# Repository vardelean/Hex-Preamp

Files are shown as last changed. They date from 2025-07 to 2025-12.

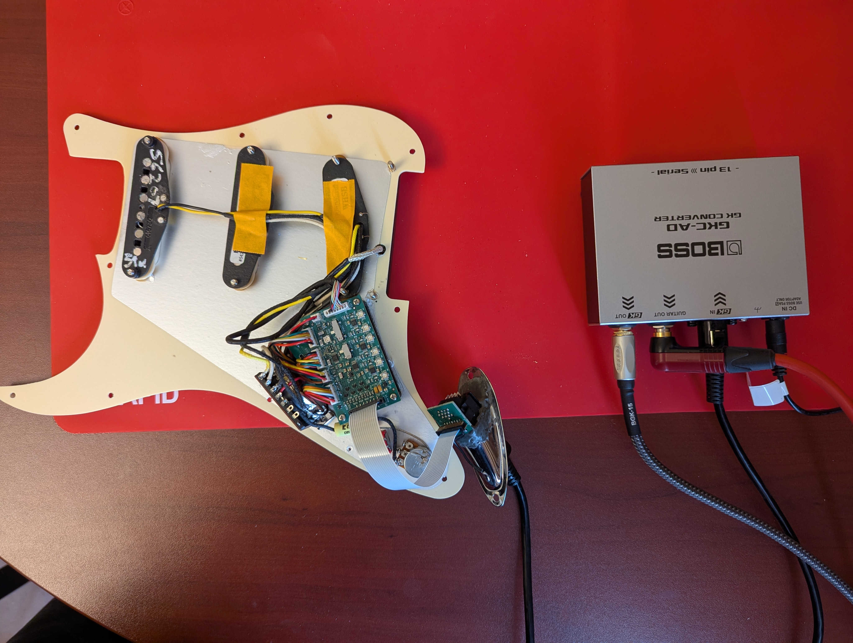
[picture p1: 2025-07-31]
Pics/Strat_Installation.jpg

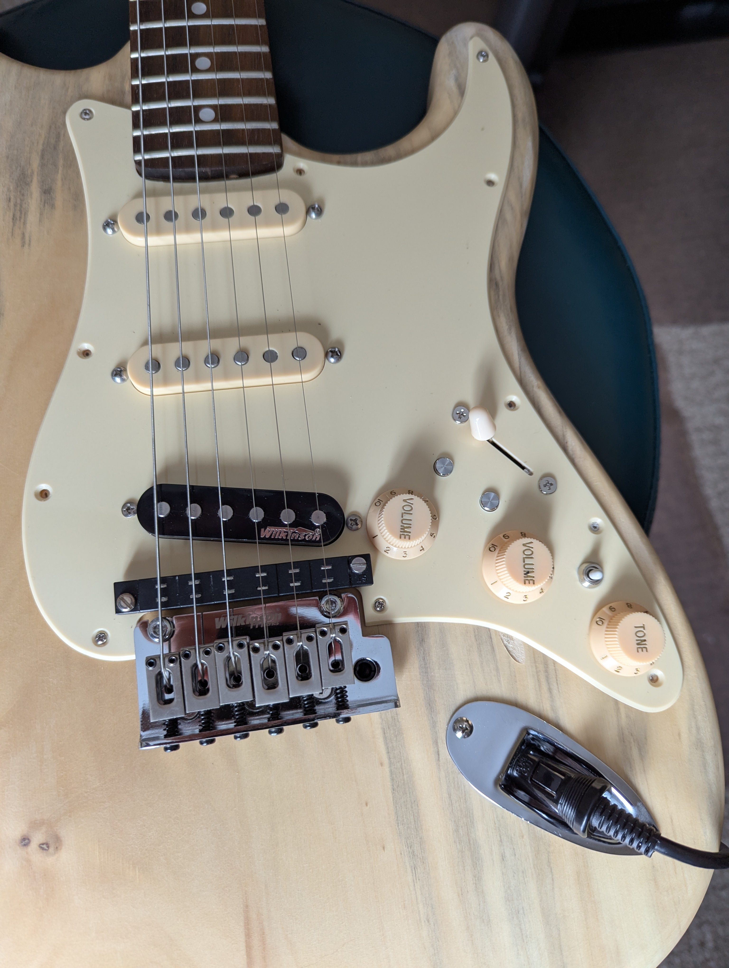
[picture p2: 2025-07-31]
Pics/Temporary install.jpg

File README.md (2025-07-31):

# Hex-Preamp
A GK-3 Compatible Hexaphonic Pickup Preamp Experiment

## Design Considerations

The motivation for this project was to build a hexaphonic preamp that is Boss GK-3 compatible but with a common Mag/Synth Volume control and a Mag/Synth Balance control. I could have used a GK-KIT-GT3 and try to modify it, but I already had a divided pickup (a hex pickup made by Shadow, left over from an ATG Luthier Kit), so to me at least, it just made sense to build the electronics.
This design is based on the original GK-3 schematic as published by Boss in their service manual. 
In addition to a common Volume control for Mag and Synth, I placed a Balance control pot with a center detent to adjust the balance between the Mag pickups and the Synth sound. Since half of this pot (P1B) works as per the original Volume control in GK-3 Synth and Mix mode, it can also be programmed for several other functions. The programming for this control is done via the Boss software, just like programming the Volume control in a GK-3. 
Only one cable is coming out of the guitar, the 13pin cable. I didn’t want 2 connectors, one for the GK-3 (13 pin) and one for the guitar’s jack. Therefore, I replaced my Strat’s jack with a 13 pin DIN connector.
Since I installed this board in a Strat, the 3 potentiometer knobs are now Volume, Balance and Tone.
The Volume and Balance work as explained above, and the Tone is placed at the output of the 5-way pickup selector switch. With this wiring, there is just one Tone pot for the 3 magnetic pickups. The Tone control has no impact on Synth sounds.

## Other Changes and Modifications to the GK-3 Design
- I used better quality opamps (lower noise, lower distortion, and lower power consumption).
- Adjustable gain for each string. I have a GK-5 installed on another Strat that I use with my VG-800, and I noticed that a hotter output from the pickups would benefit the system’s SNR and the note recognition algorithms. Since on this kit I was going to use a Shadow Hex pickup, I had no idea what the correct gain should be, so I decided for a gain trim per string.
- Adjustable gain for the guitar’s main pickups: this is to balance the mag sound compared to the Synth levels.
- Selectable input impedance for the guitar’s pickups to accommodate either SC or HB pickups (SW2). Not really needed, but I’m thinking on replacing the bridge pickup with a humbucker at one point, so this switch may come in handy.
- Selectable input capacitance for the guitar’s pickups to emulate different cable lengths (SW1). I prefer the sound of my SC pickups through a short cable. A preamp removes the cable’s capacitance impact on the pickup’s resonance frequency, so I decided to add a switch that could emulate the cable’s capacitance.
- The Volume control, P2, is a supposed to be a stereo pot, half Log / half Lin.  I couldn't find such a pot, so I decided to make my own custom pot out of two stereo pots, one Log and one Lin.
- The Balance pot, P1, is a stereo Lin pot with a center detent. 
- The schematic shows a toggle switch for the UP/DOWN selector (SW3). In my Strat implementation, I used 2 separate tactile switches instead. Either option works well.
- The wiring from the main board’s J2 connector to the 13pin DIN connector was done via an FFC cable. Feeding the FFC cable from the main board to the 13pin connector in a Strat body turned out to be a bit of a challenge. If I ever decide to make another version of this board, I may consider using a different type of cable.

## Power 
The board is powered via the 13pin connector, just like the regular GK-3 Kit. 

## Connectors
JST 1.5mm connectors everywhere except for the FPC connector.

## Files

- 13PIN_Connector_Board/Hex_Out - Files for the 13pin connector adapter board
- G13_Breakout_Board - Files for a test board, allows to look at the 13pins signals while conencted to the Boss equipment
- GI13_Hex_Preamp - Main files for the Guitar Interface 13 pin Hex Preamp
- Pics - Repository for pics and images of the board installation

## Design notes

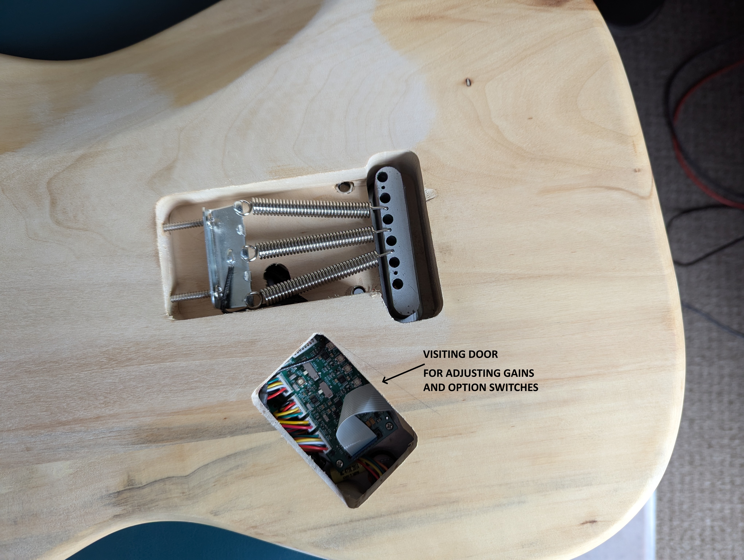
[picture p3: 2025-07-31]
Pics/Controls_Backdoor.jpg

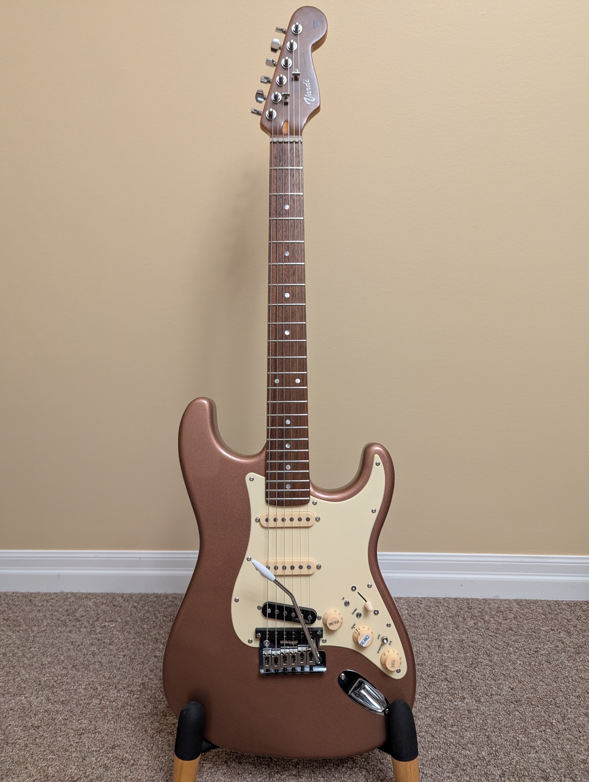
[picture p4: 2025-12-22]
Pics/GK_3_FInished_1.jpg

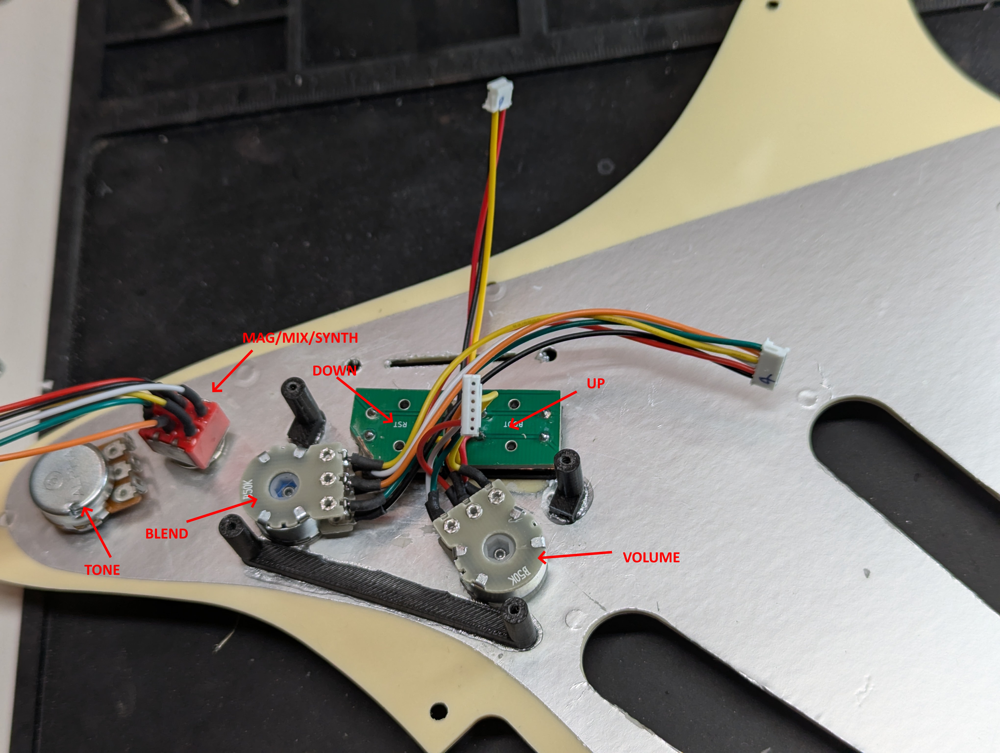
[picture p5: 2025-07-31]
Pics/Support_For_Hex_Preamp.jpg

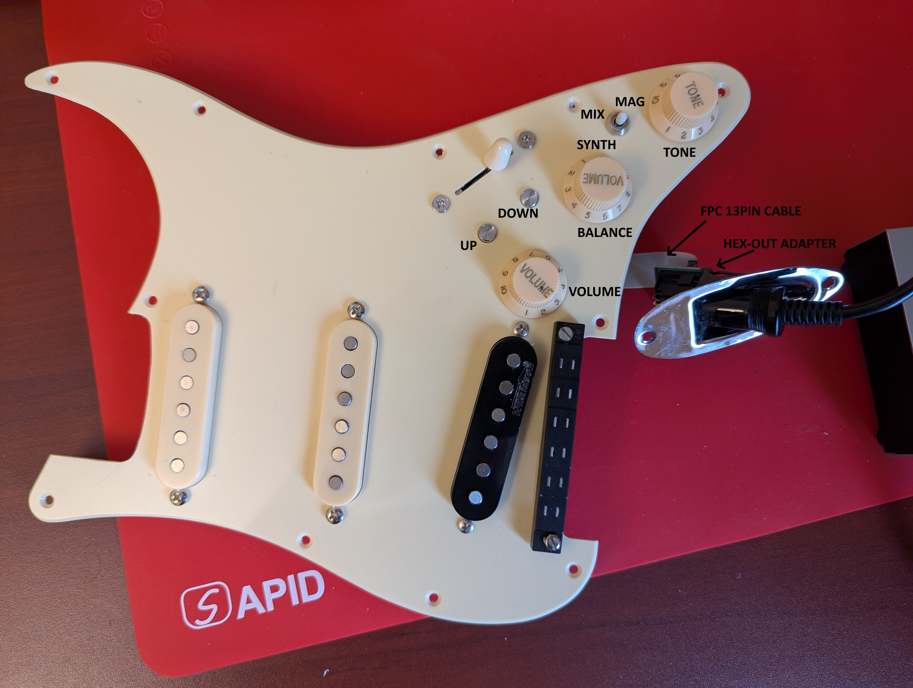
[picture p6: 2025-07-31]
Pics/Strat_Pickguard.jpg

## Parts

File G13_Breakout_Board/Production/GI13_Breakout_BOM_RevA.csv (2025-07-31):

Designator | Footprint | Quantity | Value | LCSC Part #
D1 | 0603 | 1 | +7V | 5973324507F
D2 | 0603 | 1 | -7V | 5990040007F
J1, J4 | PinHeader_1x07_P2.54mm_Vertical | 2 | Conn_01x07_Pin
J2, J3 | CUI_SDD-130J | 2 | SDD-130J | SDD-130J
J5 | PinHeader_1x02_P2.54mm_Vertical | 1 | Conn_01x07_Pin
R1, R2 | 0603 | 2 | 1K

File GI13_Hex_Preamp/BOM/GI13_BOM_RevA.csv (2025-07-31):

Reference | Value | Datasheet | Footprint | Qty | DNP | MPN | Description
C1,C2,C3,C4,C5,C14,C15,C16,C23,C25,C26,C29,C30,C35 | 0.1u | ~ | Capacitor_SMD:C_0603_1608Metric | 14 |  |  | Unpolarized capacitor
C6,C7,C8,C9,C10,C11,C28 | 220p | ~ | Capacitor_SMD:C_0603_1608Metric | 7 |  |  | Unpolarized capacitor
C12,C13 | 10u | ~ | Capacitor_Tantalum_SMD:CP_EIA-3216-18_Kemet-A | 2 |  |  | Polarized capacitor
C17,C18,C19,C20,C21,C22,C36,C37 | 1n0 | ~ | Capacitor_SMD:C_0603_1608Metric | 8 |  |  | Unpolarized capacitor
C24 | 10n | ~ | Capacitor_SMD:C_0603_1608Metric | 1 |  |  | Unpolarized capacitor
C27 | 470p | ~ | Capacitor_SMD:C_0603_1608Metric | 1 |  |  | Unpolarized capacitor
C31 | 47n | ~ | Capacitor_SMD:C_0805_2012Metric | 1 |  | C0805C473K3GECTU | Ceramic Capacitor COG
C32 | 47p | ~ | Capacitor_SMD:C_0603_1608Metric | 1 |  |  | Unpolarized capacitor
C33,C34,C38,C39 | 0.22u | https://search.murata.co.jp/Ceramy/image/img/A01X/G101/ENG/GRM31C5C1E224JE02-01A.pdf | Capacitor_SMD:C_1206_3216Metric | 4 |  | GRM31C5C1E224JE02L | CAP CER 0.22UF 25V C0G/NP0 1206
D1,D2,D3,D4,D5,D6,D7,D8 | 1SS302 | https://www.digikey.ca/en/models/5810203 | User_1:USM_TOS | 8 |  |  | DIODE ARRAY GP 80V 100MA SC-70
H1,H2,H3,H4 | MountingHole | ~ | MountingHole:MountingHole_2.2mm_M2_DIN965_Pad_TopBottom | 4 |  |  | Mounting Hole with connection
J1 | Conn_01x08_Pin_Box | ~ | Connector_JST:JST_ZH_B8B-ZR_1x08_P1.50mm_Vertical | 1 |  | B8B-ZH-K-S | Generic connector, single row, 01x08, script generated
J2 | SFW14S-2STE1LF | https://cdn.amphenol-cs.com/media/wysiwyg/files/documentation/datasheet/flex/flexconnectors_100mm_sfw_s.pdf | Connector_FFC-FPC:AMPHENOL_SFW14S-2STE1LF | 1 |  | SFW14S-2STE1LF | CONN FFC FPC VERT 14POS 1MM SMD
J3 | Conn_01x02_Pin | ~ | Connector_JST:JST_ZH_B2B-ZR_1x02_P1.50mm_Vertical | 1 |  |  | Generic connector, single row, 01x02, script generated
J4,J5,J7 | Conn_01x06_Pin | ~ | Connector_JST:JST_ZH_B6B-ZR_1x06_P1.50mm_Vertical | 3 |  |  | Generic connector, single row, 01x06, script generated (kicad-library-utils/schlib/autogen/connector/)
J6 | Conn_01x03 | ~ | Connector_JST:JST_ZH_B3B-ZR_1x03_P1.50mm_Vertical | 1 |  |  | Generic connector, single row, 01x03, script generated (kicad-library-utils/schlib/autogen/connector/)
R1,R2,R3,R4,R5,R6,R24,R29 | 5K1 | ~ | Resistor_SMD:R_0603_1608Metric | 8 |  |  | Resistor, US symbol
R7,R8,R9,R10,R11,R12,R13,R14 | 1K0 | ~ | Resistor_SMD:R_0603_1608Metric | 8 |  |  | Resistor, US symbol
R15,R16,R17 | 100R | ~ | Resistor_SMD:R_0603_1608Metric | 3 |  |  | Resistor, US symbol
R18,R20,R23,R26,R30,R33 | 51R | ~ | Resistor_SMD:R_0603_1608Metric | 6 |  |  | Resistor, US symbol
R19,R27 | 220K | ~ | Resistor_SMD:R_0603_1608Metric | 2 |  |  | Resistor, US symbol
R21,R22 | 249K | ~ | Resistor_SMD:R_0603_1608Metric | 2 |  |  | Resistor, US symbol
R25 | 10K | ~ | Resistor_SMD:R_0603_1608Metric | 1 |  |  | Resistor, US symbol
R28 | 5M1 | ~ | Resistor_SMD:R_0603_1608Metric | 1 |  |  | Resistor, US symbol
R31 | 6K81 | ~ | Resistor_SMD:R_0603_1608Metric | 1 |  |  | Resistor, US symbol
R32,R37 | 18K | ~ | Resistor_SMD:R_0603_1608Metric | 2 |  |  | Resistor, US symbol
R34 | 9K42 | ~ | Resistor_SMD:R_0603_1608Metric | 1 |  |  | Resistor, US symbol
R35 | 1K8 | ~ | Resistor_SMD:R_0603_1608Metric | 1 |  |  | Resistor, US symbol
R36 | 1K43 | ~ | Resistor_SMD:R_0603_1608Metric | 1 |  |  | Resistor, US symbol
RV1,RV2,RV3,RV4,RV5,RV6,RV7 | 20K | https://www.bourns.com/docs/Product-Datasheets/pvg3.pdf | Potentiometer_SMD:TRIM_PVG3G203C01R00 | 7 |  | PVG3G203C01R00 | TRIMMER 20K OHM 0.25W GW TOP ADJ
SW1 | CL-SB-13B-11T | https://www.nidec-copal-electronics.com/e/catalog/switch/cl-sb.pdf | Switches:CLSB13B11T | 1 |  | CLSB13B11T | Slide Switches slide , 1 pole 3 cont., side set., gull-wing, silver contact, 2mm knob
SW2 | CL-SB-12B-11T | https://www.nidec-copal-electronics.com/e/catalog/switch/cl-sb.pdf | Switches:CLSB12B01T | 1 |  | CLSB12B01T | Slide Switches slide , 1 pole 3 cont., side set., gull-wing, silver contact, 2mm knob
U1 | MCP1754S-5002xCB | http://ww1.microchip.com/downloads/en/DeviceDoc/20002276C.pdf | Package_TO_SOT_SMD:SOT-23 | 1 |  | MCP1754ST-5002E/CB | Fixed 150mA Low Dropout Voltage Regulator, Positive, 5V output, SOT-23
U2,U3,U4,U7 | OPA1692 | https://www.ti.com/lit/gpn/OPA1692 | Package_SO:MSOP-8_3x3mm_P0.65mm | 4 |  | OPA1692IDGKR | Audio Amplifier 2 Circuit Rail-to-Rail 8-VSSOP
U5 | TLV9302xDGK | https://www.ti.com/lit/ds/symlink/tlv9302.pdf | Package_SO:MSOP-8_3x3mm_P0.65mm | 1 |  | TLV9302IDGK | 40-V, 1-MHz, RRO Operational Amplifiers for Cost-Sensitive Systems, VSSOP-8
U6 | TLV9151IDBVR | https://www.ti.com/lit/gpn/tlv9151 | Package_TO_SOT_SMD:SOT-23-5 | 1 |  | TLV9151IDBVR | IC OPAMP GP 1 CIRCUIT SOT23-5

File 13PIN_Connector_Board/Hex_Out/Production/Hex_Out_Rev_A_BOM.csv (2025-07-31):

Designator | Footprint | Quantity | Value | LCSC Part #
J1 | AMPHENOL_SFW14S-2STE1LF | 1 | Conn_02x07_Odd_Even
J4 | CUI_SDD-130J | 1 | SDD-130J | SDD-130J

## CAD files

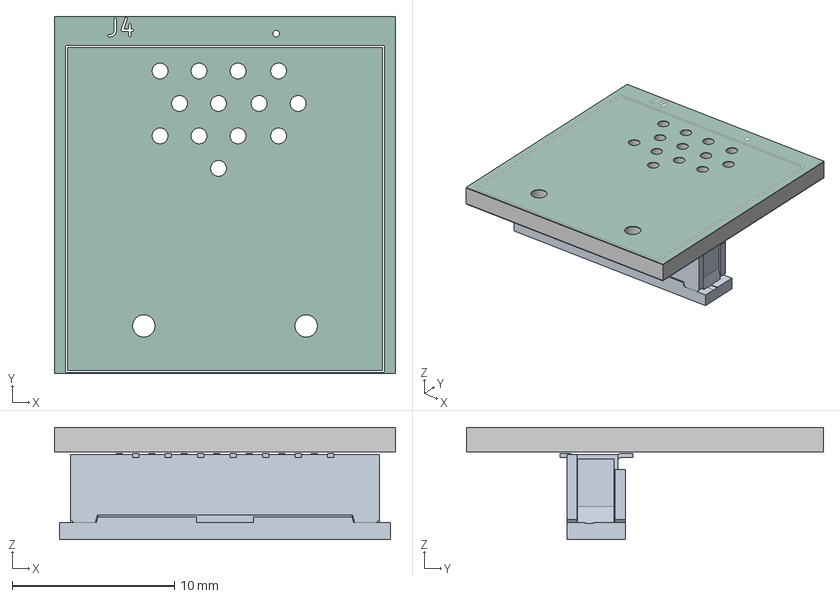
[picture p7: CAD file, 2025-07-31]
13PIN_Connector_Board/Hex_Out/Hex_Out_RevA_3D.step
21.0 x 22.0 x 6.97 mm
Hex_Out_RevA_3D 1.1
Hex_Out_silkscreen
Hex_Out_soldermask
Hex_Out_PCB

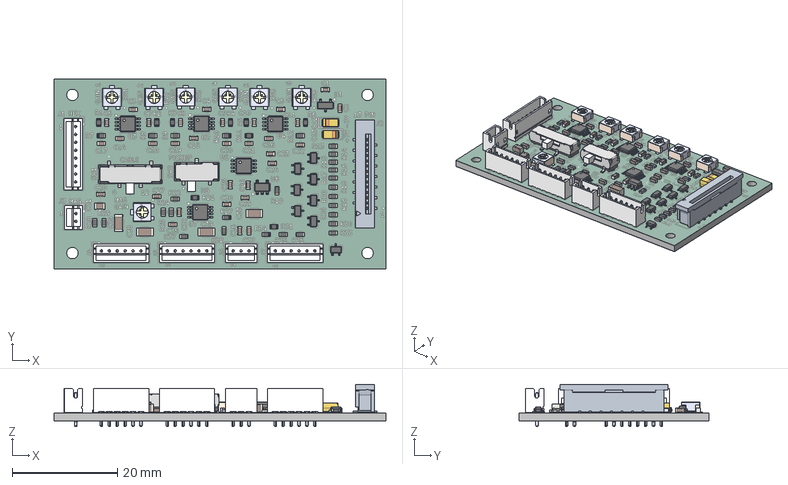
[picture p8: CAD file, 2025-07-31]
GI13_Hex_Preamp/3D/GI13_3D_RevA.step
63.0 x 36.0 x 8.00 mm
C_1206_3216Metric x 4
C_0603_1608Metric x 32
R_0603_1608Metric x 37
PVG3G203C01R00 x 7
BxB-ZR_3
pin_straight x 20
pin_Bent x 11
SOT-23-5
BxB-ZR_2
BxB-ZR_6 x 3
GI13_3D_RevA 1.33
MSOP-8_3x3mm_P0.65mm x 5
13B-11_c
3Side setting_s
SOT-23
C_0805_2012Metric
BxB-ZR_8
sc70-3 x 8
CP_EIA-3216-18_Kemet-A x 2
12B-11_c
2Side setting_s
GI13_silkscreen
GI13_soldermask
GI13_PCB

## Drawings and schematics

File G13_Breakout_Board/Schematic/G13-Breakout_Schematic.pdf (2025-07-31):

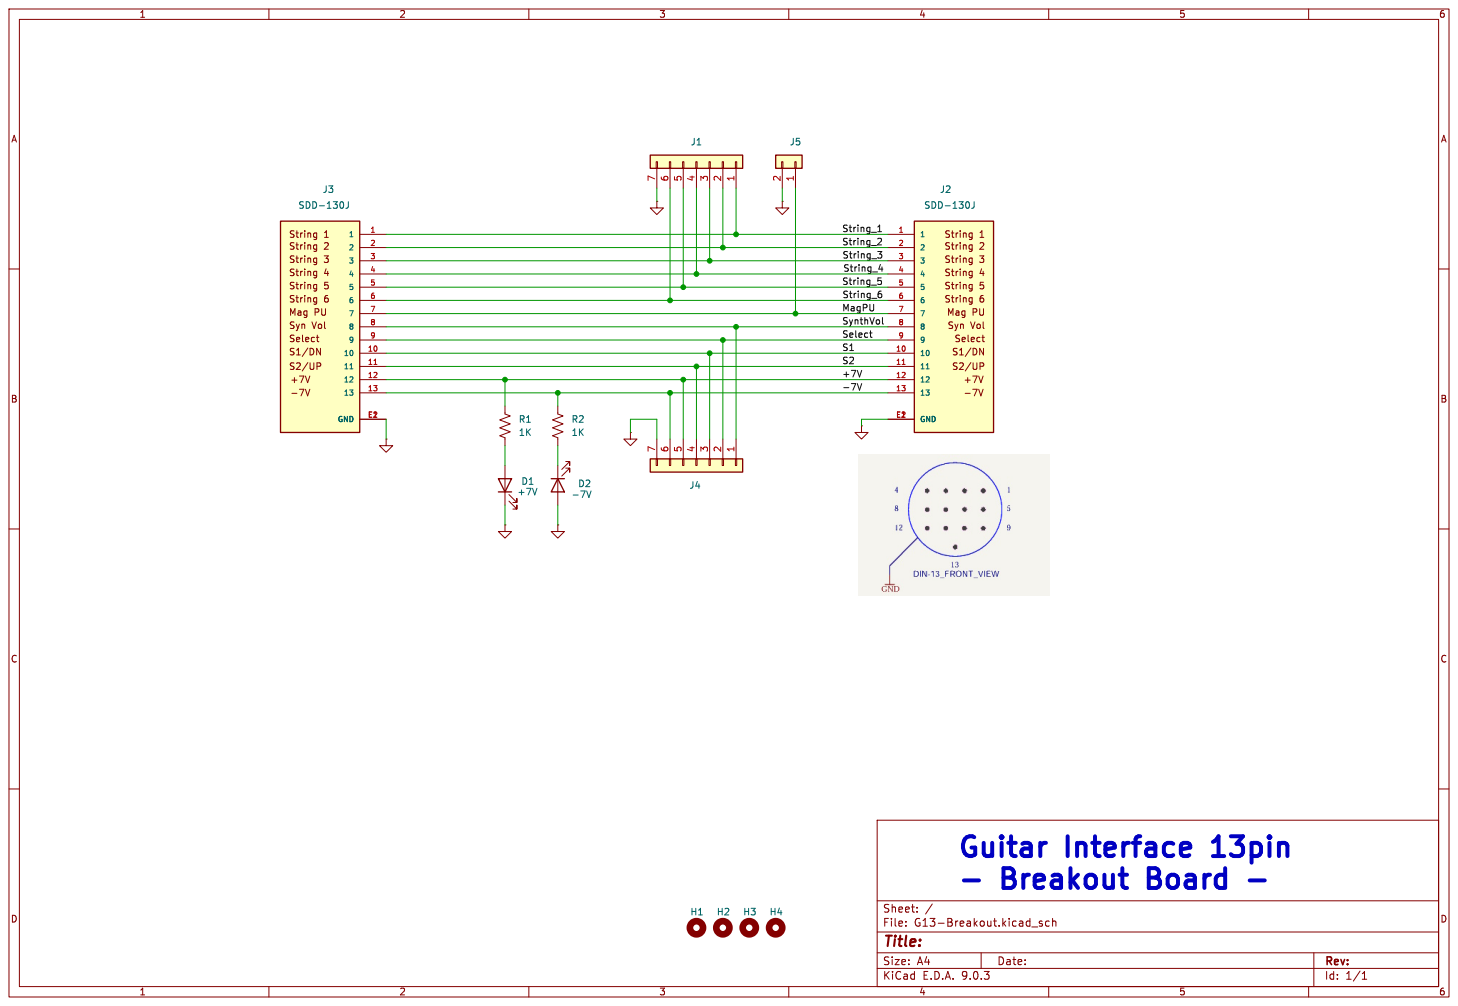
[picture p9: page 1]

String 1 String 2 String 3 String 4 String 5 String 6 Mag PU

3 | String_3 3
7 | String_4 +7V MagPU 7
5 | String_5 5

Syn Vol Select S1/DN

10 10
11 11
12 12

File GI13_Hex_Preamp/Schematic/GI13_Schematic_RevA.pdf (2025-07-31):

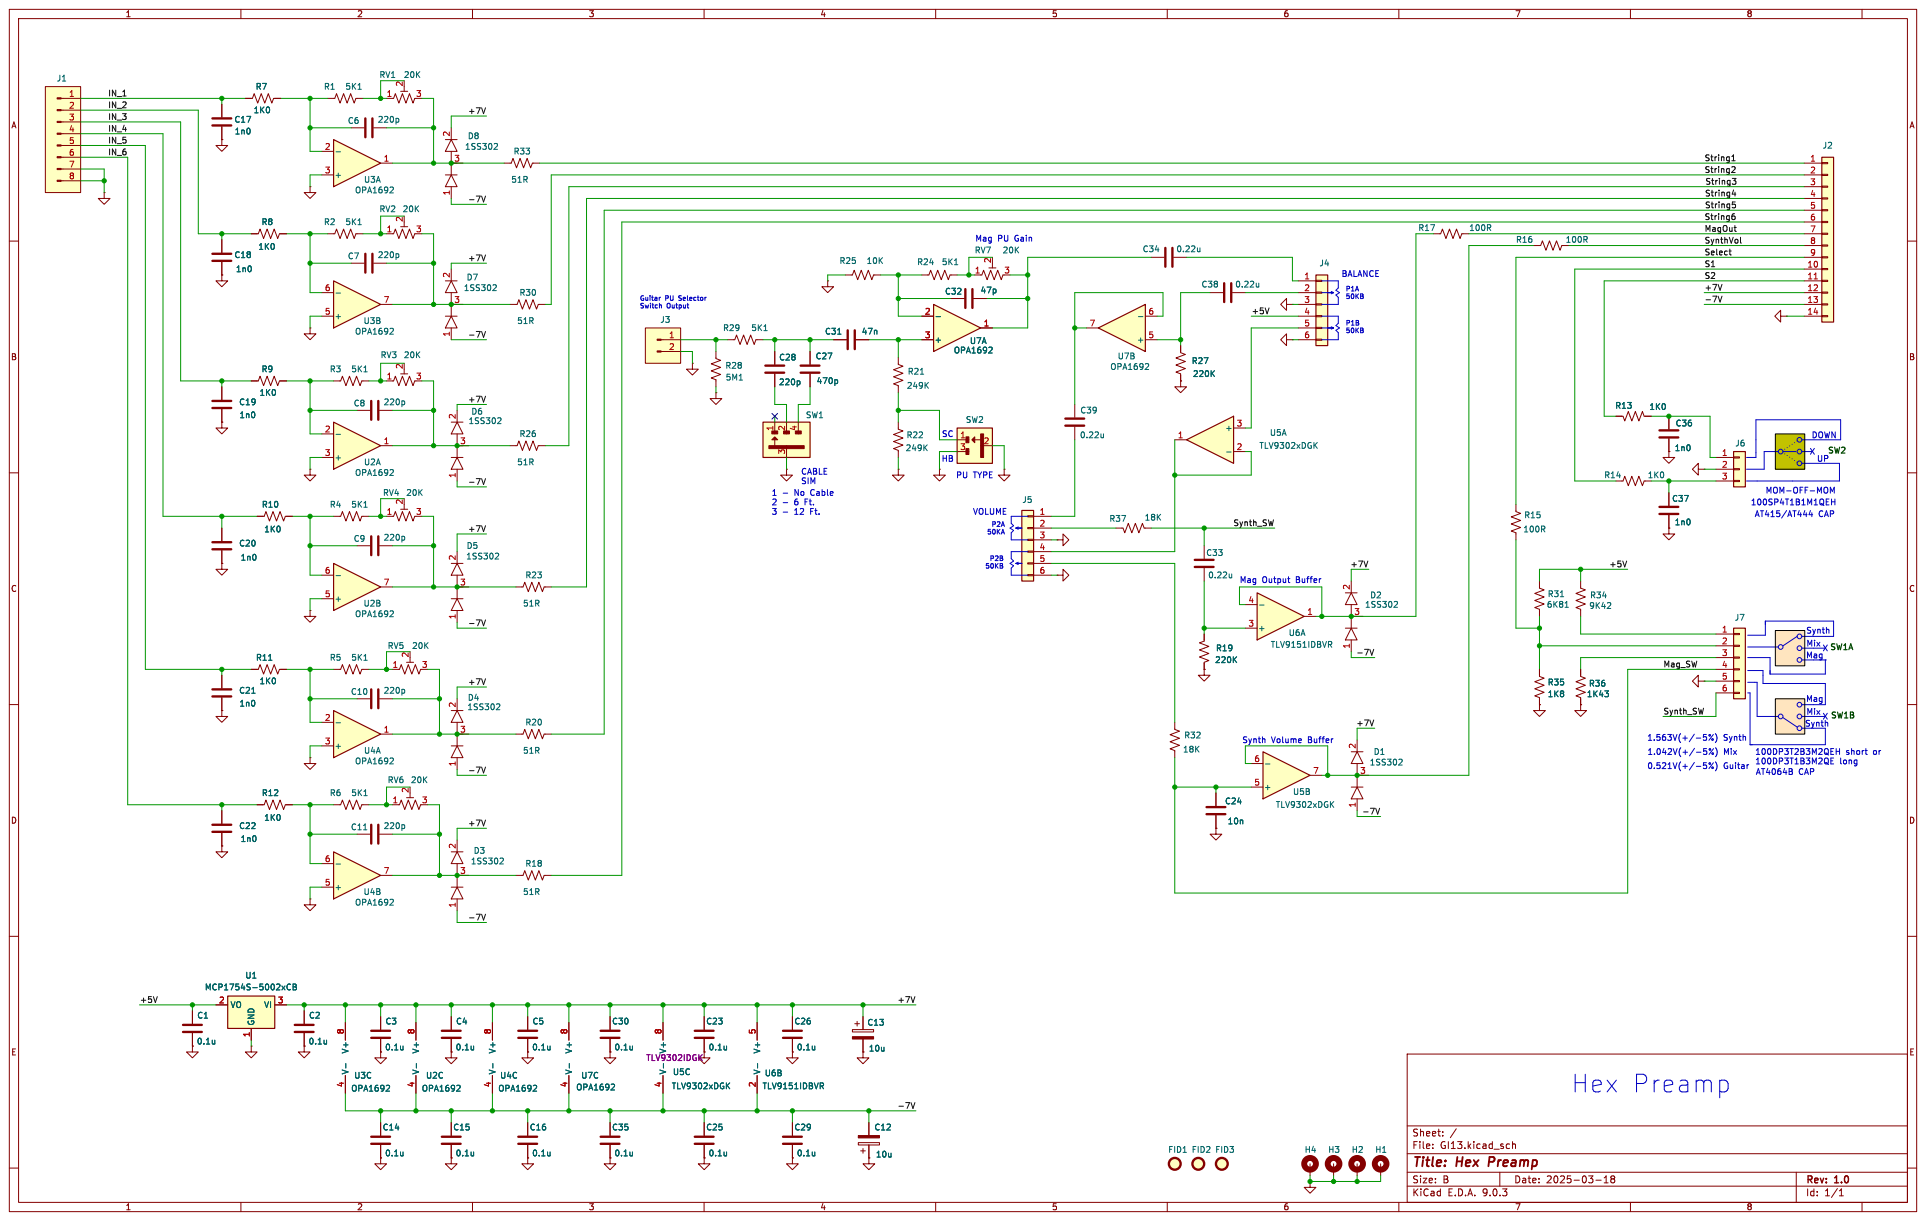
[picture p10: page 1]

Mag PU Gain PU TYPE

Synth Mix Hex Preamp

File: GI13.kicad_sch Sheet: /
Id: 1/1 Title: Hex Preamp

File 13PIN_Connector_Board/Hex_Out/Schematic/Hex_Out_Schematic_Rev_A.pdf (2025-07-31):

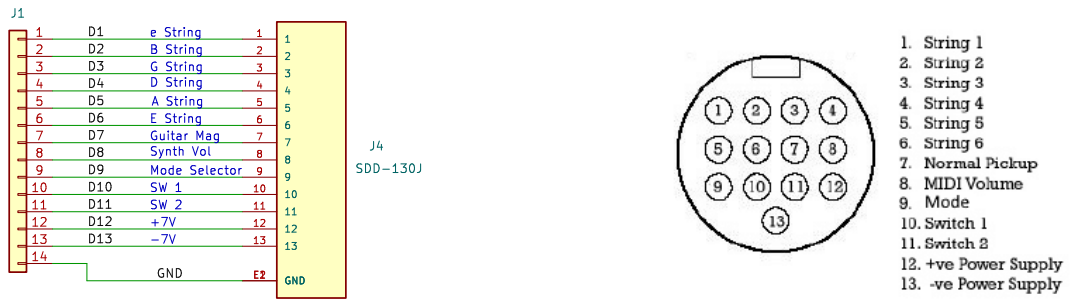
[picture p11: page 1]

SW 1 SW 2 Mode Selector

File: Hex_Out.kicad_sch Sheet: /
Id: 1/1 Title: 13 Pin Connector Board
